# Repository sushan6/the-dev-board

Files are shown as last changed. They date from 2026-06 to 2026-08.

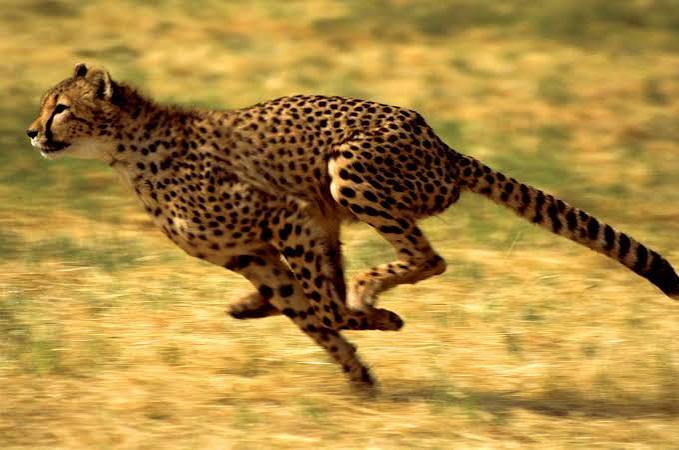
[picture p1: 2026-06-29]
assets/images (1).png

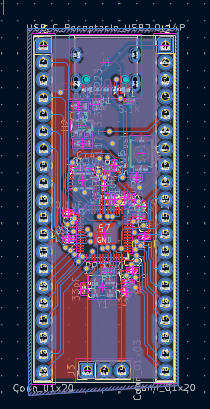
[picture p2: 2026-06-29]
assets/pcb image.PNG

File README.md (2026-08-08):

# Sushan's dev board 

This development board is designed to be a compact, reliable prototyping platform using the RP2040 microcontroller. It handles power management, high-speed external memory routing, and precise clocking, making it ready for custom embedded software applications.

## Key Features

* Microcontroller: Based on the RP2040 chip, bringing twin-core processing capabilities to a custom hardware layout.
* Power Management: Driven by a modern USB-C receptacle for both power delivery and data interfacing, regulated down to a clean three-point-three volts using an onboard linear regulator.
* External Storage: Incorporates external flash memory connected over a quad serial peripheral interface, giving ample room for large programs and data storage.
* Clock Source: Utilises a twelve megahertz crystal oscillator circuit to ensure stable and highly accurate clock timing for the microcontroller.
* Input and Output Breakouts: Exposes general-purpose input/output pins to dual-row pin headers, providing quick access for connecting sensors, displays, and external components.
* There are 40 pins externally for data
* SD card reader 
## Hardware Design and Previews

### Schematic Layout
The schematic is divided into clean functional blocks including power management, flash memory wiring, crystal clock generation, and pin mappings. 

schematics1

---

### PCB Layout and 3D Visualisations
The physical layout focuses on tight trace routing, proper decoupling capacitor placement for power stability, and optimised signal paths. 

pcb image1

#### Board Front View

front-3d-pcb1

#### Board Back View

back-3d-pcb1

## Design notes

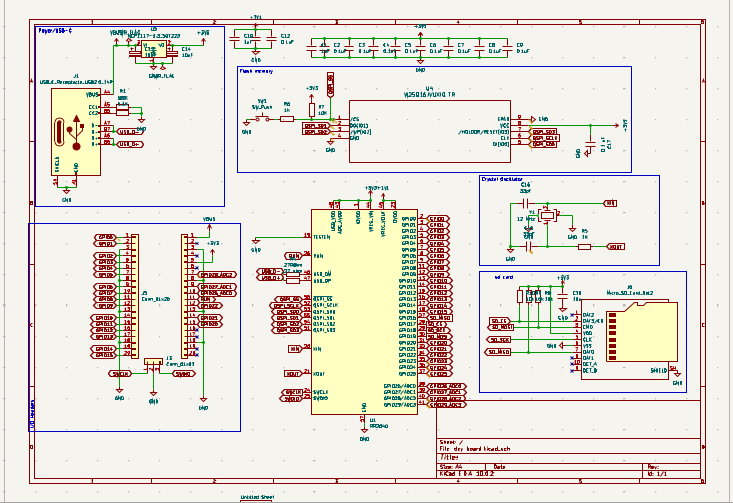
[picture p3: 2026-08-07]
assets/schematics.PNG

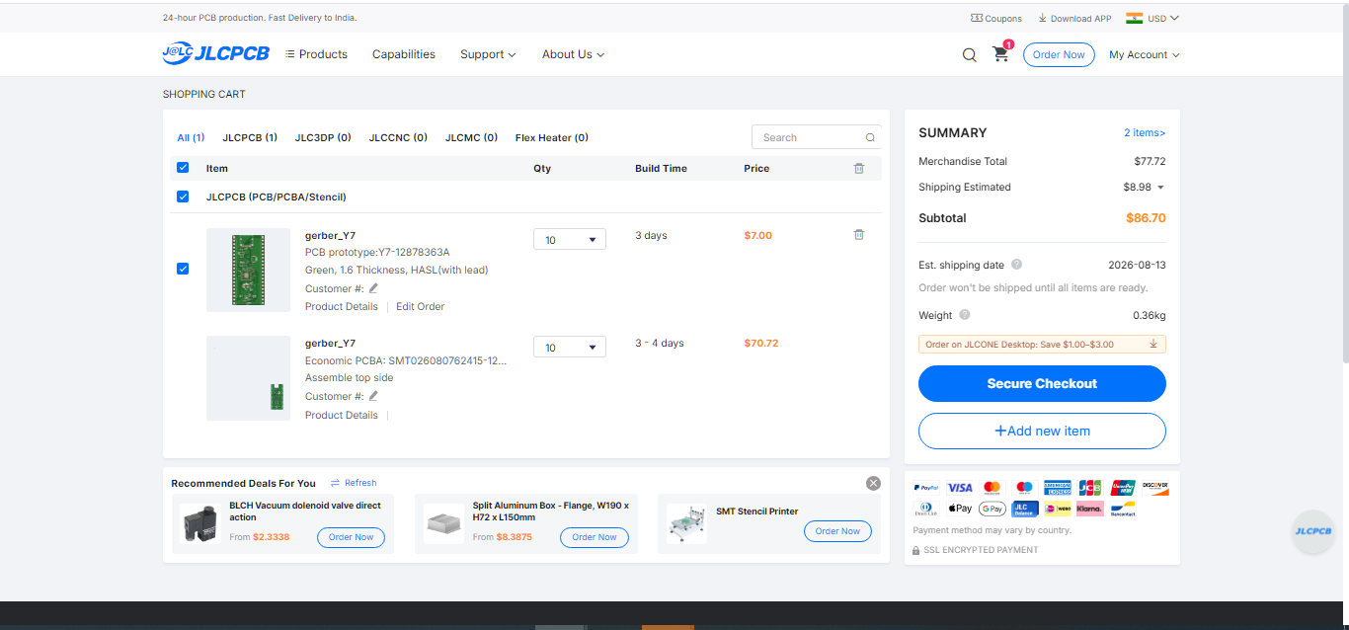
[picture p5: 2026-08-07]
assets/cart-jlcpcb.PNG

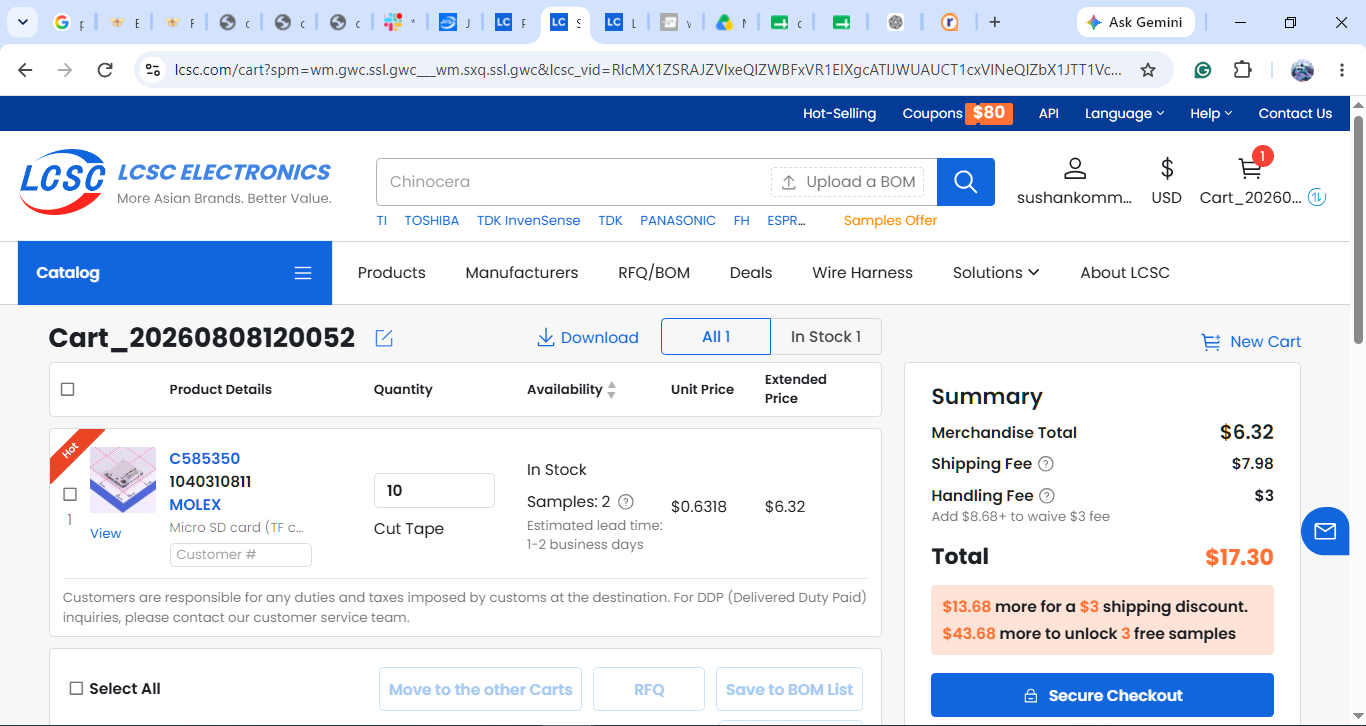
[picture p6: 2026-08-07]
assets/cart-lcsc.PNG

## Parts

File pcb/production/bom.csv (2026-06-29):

Designator | Footprint | Quantity | Value | LCSC Part #
C1, C10 | 0402 | 2 | 1uF
C11, C12, C2, C3, C4, C5, C6, C7, C8, C9 | 0402 | 10 | 0.1uF
C13, C14 | 0603 | 2 | 10uF
C15, C16 | 0402 | 2 | 33pF
C17 | 0402 | 1 | 0.1 uF
J1 | USB_C_Receptacle_HRO_TYPE-C-31-M-12 | 1 | USB_C_Receptacle_USB2.0_14P
J2, J5 | PinHeader_1x20_P2.54mm_Vertical | 2 | Conn_01x20
J3 | PinHeader_1x03_P2.54mm_Vertical | 1 | Conn_01x03
R1, R2 | 0402 | 2 | 5.1K
R3, R4 | 0402 | 2 | 27 ohm
R5, R6 | 0402 | 2 | 1K
R7 | 0402 | 1 | 10K
SW1 | SW_Push_SPST_NO_Alps_SKRK | 1 | SW_Push
U1 | QFN-56-1EP_7x7mm_P0.4mm_EP3.2x3.2mm | 1 | RP2040
U2 | SOT-23 | 1 | NCP1117-3.3_SOT223
U4 | Winbond_USON-8-1EP_3x2mm_P0.5mm_EP0.2x1.6mm | 1 | W25Q16JVUXIQ TR
Y1 | Crystal_SMD_3225-4Pin_3.2x2.5mm | 1 | 12 MHz

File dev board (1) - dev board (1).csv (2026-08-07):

Id | Designator | Footprint | Quantity | Comment | Supplier and ref
1 | C1, C10 | C_0402_1005Metric | 2 | 1uF
2 | C2, C3, C4, C5, C6, C7, C8, C9, C11, C12 | C_0402_1005Metric | 10 | 0.1uF
3 | C13, C14 | C_0603_1608Metric | 2 | 10uF
4 | C15, C16 | C_0402_1005Metric | 2 | 33pF
5 | C17 | C_0402_1005Metric | 1 | 0.1 uF
6 | C18 | C_0603_1608Metric | 1 | 10u
7 | C19 | C_0402_1005Metric | 1 | 0.1uf
8 | J1 | USB_C_Receptacle_HRO_TYPE-C-31-M-12 | 1 | USB_C_Receptacle_USB2.0_14P
9 | J2, J5 | PinHeader_1x20_P2.54mm_Vertical | 2 | Conn_01x20
10 | J3 | PinHeader_1x03_P1.27mm_Vertical_SMD_Pin1Left | 1 | Conn_01x03
11 | J4 | microSD_HC_Molex_104031-0811 | 1 | 104031-0811
12 | R1, R2 | R_0402_1005Metric | 2 | 5.1K
13 | R3, R4 | R_0402_1005Metric | 2 | 27 ohm
14 | R5 | R_0402_1005Metric | 1 | 1K
15 | R6 | R_0402_1005Metric | 1 | 1k
16 | R7 | R_0402_1005Metric | 1 | 10K
17 | R8, R9, R10 | R_0402_1005Metric | 3 | 10k
18 | SW1 | SW_Push_SPST_NO_Alps_SKRK | 1 | SW_Push
19 | U1 | QFN-56-1EP_7x7mm_P0.4mm_EP3.2x3.2mm | 1 | RP2040
20 | U2 | SOT-23 | 1 | NCP1117-3.3_SOT223
21 | U4 | Winbond_USON-8-1EP_3x2mm_P0.5mm_EP0.2x1.6mm | 1 | W25Q16JVUXIQ TR
22 | Y1 | Crystal_SMD_3225-4Pin_3.2x2.5mm | 1 | 12 MHz

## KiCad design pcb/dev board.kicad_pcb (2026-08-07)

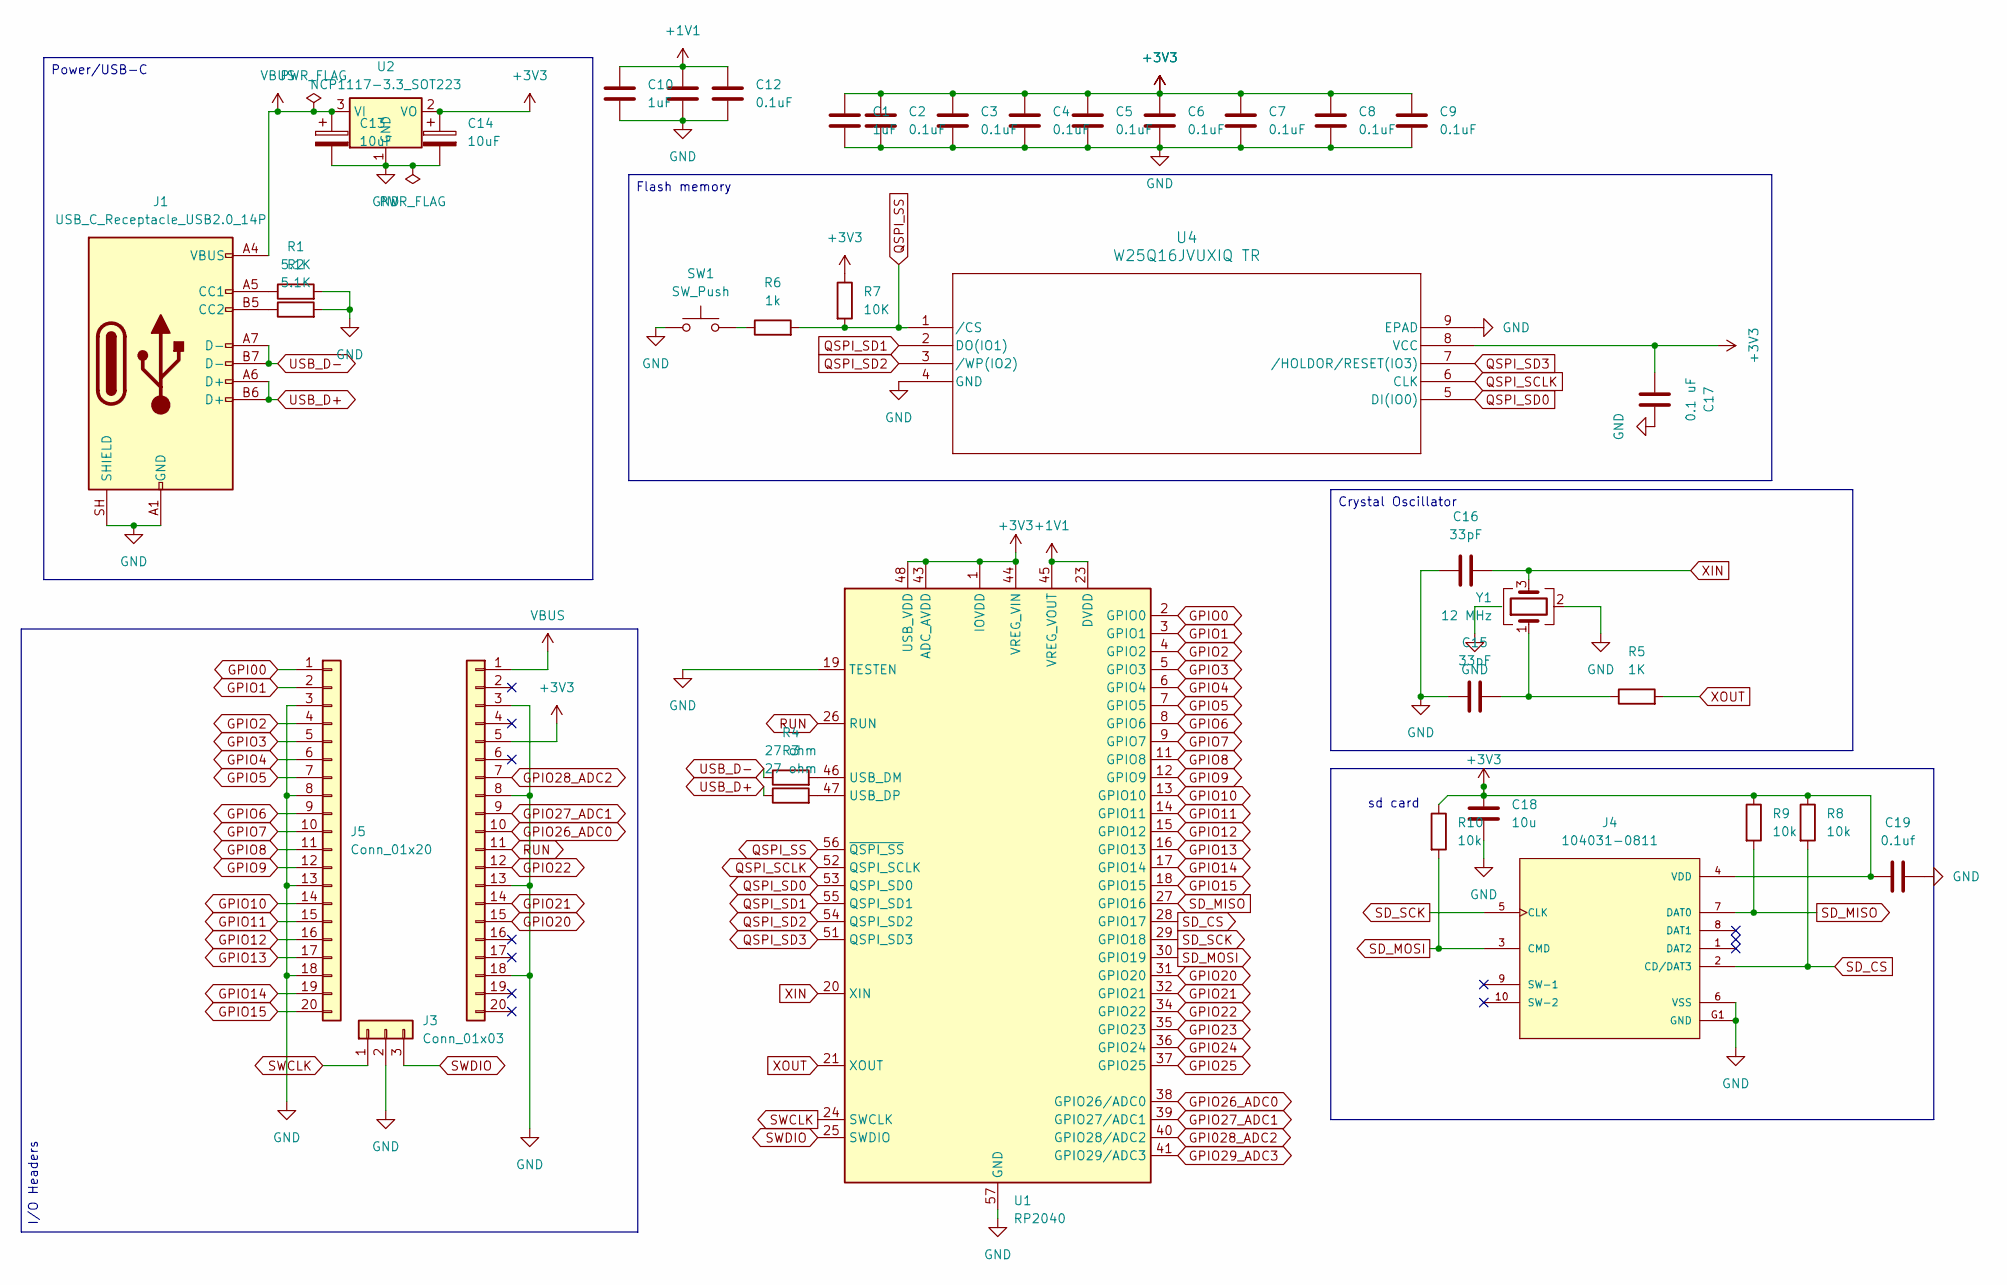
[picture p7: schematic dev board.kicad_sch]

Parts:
C1, C10: 1uF; C_0402_1005Metric
C2, C3, C4, C5, C6, C7, C8, C9, C11, C12: 0.1uF; C_0402_1005Metric
C13, C14: 10uF; C_0603_1608Metric
C15, C16: 33pF; C_0402_1005Metric
C17: 0.1 uF; C_0402_1005Metric
C18: 10u; C_0603_1608Metric
C19: 0.1uf; C_0402_1005Metric
J1: USB_C_Receptacle_USB2.0_14P; USB_C_Receptacle_HRO_TYPE-C-31-M-12
J2, J5: Conn_01x20; PinHeader_1x20_P2.54mm_Vertical
J3: Conn_01x03; PinHeader_1x03_P1.27mm_Vertical_SMD_Pin1Left
J4: 104031-0811; microSD_HC_Molex_104031-0811; PARTREV B2
R1, R2: 5.1K; R_0402_1005Metric
R3, R4: 27 ohm; R_0402_1005Metric
R5: 1K; R_0402_1005Metric
R6: 1k; R_0402_1005Metric
R7: 10K; R_0402_1005Metric
R8, R9, R10: 10k; R_0402_1005Metric
SW1: SW_Push; SW_Push_SPST_NO_Alps_SKRK
U1: RP2040; QFN-56-1EP_7x7mm_P0.4mm_EP3.2x3.2mm
U2: NCP1117-3.3_SOT223; SOT-23
U4: W25Q16JVUXIQ TR; Winbond_USON-8-1EP_3x2mm_P0.5mm_EP0.2x1.6mm
Y1: 12 MHz; Crystal_SMD_3225-4Pin_3.2x2.5mm

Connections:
+1V1: C10.1, C11.1, C12.1, U1.23 (DVDD), U1.45 (VREG_VOUT), U1.50 (DVDD)
+3V3: C1.1, C2.1, C3.1, C4.1, C5.1, C6.1, C7.1, C8.1, C9.1, C14.1, C17.1, C18.1, C19.2, J2.5, J4.4 (VDD), R7.1, R8.1, R9.1, R10.1, U1.1 (IOVDD), U1.10 (IOVDD), U1.22 (IOVDD), U1.33 (IOVDD), U1.42 (IOVDD), U1.43 (ADC_AVDD), U1.44 (VREG_VIN), U1.48 (USB_VDD), U1.49 (IOVDD), U2.2 (VO), U4.8 (VCC)
GND: C1.2, C2.2, C3.2, C4.2, C5.2, C6.2, C7.2, C8.2, C9.2, C10.2, C11.2, C12.2, C13.2, C14.2, C15.1, C16.1, C17.2, C18.2, C19.1, J1.A1 (GND), J1.A12 (GND), J1.B1 (GND), J1.B12 (GND), J1.SH (SHIELD), J2.3, J2.8, J2.13, J2.18, J3.2, J4.6 (VSS), J4.G1 (GND), J4.G2 (GND), J4.G3 (GND), J4.G4 (GND), J5.3, J5.8, J5.13, J5.18, R1.2, R2.2, SW1.1, U1.19 (TESTEN), U1.57 (GND), U2.1 (GND), U4.4 (GND), U4.9 (EPAD), Y1.2 (G), Y1.4 (G)
GPI00: J5.1
GPI028_ADC2: U1.40 (GPIO28/ADC2)
GPIO0: U1.2 (GPIO0)
GPIO1: J5.2, U1.3 (GPIO1)
GPIO2: J5.4, U1.4 (GPIO2)
GPIO3: J5.5, U1.5 (GPIO3)
GPIO4: J5.6, U1.6 (GPIO4)
GPIO5: J5.7, U1.7 (GPIO5)
GPIO6: J5.9, U1.8 (GPIO6)
GPIO7: J5.10, U1.9 (GPIO7)
GPIO8: J5.11, U1.11 (GPIO8)
GPIO9: J5.12, U1.12 (GPIO9)
GPIO10: J5.14, U1.13 (GPIO10)
GPIO11: J5.15, U1.14 (GPIO11)
GPIO12: J5.16, U1.15 (GPIO12)
GPIO13: J5.17, U1.16 (GPIO13)
GPIO14: J5.19, U1.17 (GPIO14)
GPIO15: J5.20, U1.18 (GPIO15)
GPIO20: J2.15, U1.31 (GPIO20)
GPIO21: J2.14, U1.32 (GPIO21)
GPIO22: J2.12, U1.34 (GPIO22)
GPIO23: U1.35 (GPIO23)
GPIO24: U1.36 (GPIO24)
GPIO25: U1.37 (GPIO25)
GPIO26_ADC0: J2.10, U1.38 (GPIO26/ADC0)
GPIO27_ADC1: J2.9, U1.39 (GPIO27/ADC1)
GPIO28_ADC2: J2.7
GPIO29_ADC3: U1.41 (GPIO29/ADC3)
unnamed: C15.2, R5.1, Y1.1
unnamed: J1.A5 (CC1), R1.1
unnamed: J1.B5 (CC2), R2.1
unnamed: R6.1, SW1.2
unnamed: R4.2, U1.46 (USB_DM)
unnamed: R3.2, U1.47 (USB_DP)
QSPI_SCLK: U1.52 (QSPI_SCLK), U4.6 (CLK)
QSPI_SD0: U1.53 (QSPI_SD0), U4.5 (DI(IO0))
QSPI_SD1: U1.55 (QSPI_SD1), U4.2 (DO(IO1))
QSPI_SD2: U1.54 (QSPI_SD2), U4.3 (/WP(IO2))
QSPI_SD3: U1.51 (QSPI_SD3), U4.7 (/HOLDOR/RESET(IO3))
QSPI_SS: R6.2, R7.2, U1.56 (~QSPI_SS), U4.1 (/CS)
RUN: J2.11, U1.26 (RUN)
SD_CS: J4.2 (CD/DAT3), R8.2, U1.28 (GPIO17)
SD_MISO: J4.7 (DAT0), R9.2, U1.27 (GPIO16)
SD_MOSI: J4.3 (CMD), R10.2, U1.30 (GPIO19)
SD_SCK: J4.5 (CLK), U1.29 (GPIO18)
SWCLK: J3.1, U1.24 (SWCLK)
SWDIO: J3.3, U1.25 (SWDIO)
USB_D+: J1.A6 (D+), J1.B6 (D+), R3.1
USB_D-: J1.A7 (D-), J1.B7 (D-), R4.1
VBUS: C13.1, J1.A4 (VBUS), J1.A9 (VBUS), J1.B4 (VBUS), J1.B9 (VBUS), J2.1, U2.3 (VI)
XIN: C16.2, U1.20 (XIN), Y1.3
XOUT: R5.2, U1.21 (XOUT)

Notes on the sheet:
sd card
Power/USB-C
I/O Headers
Flash memory
Crystal Oscillator

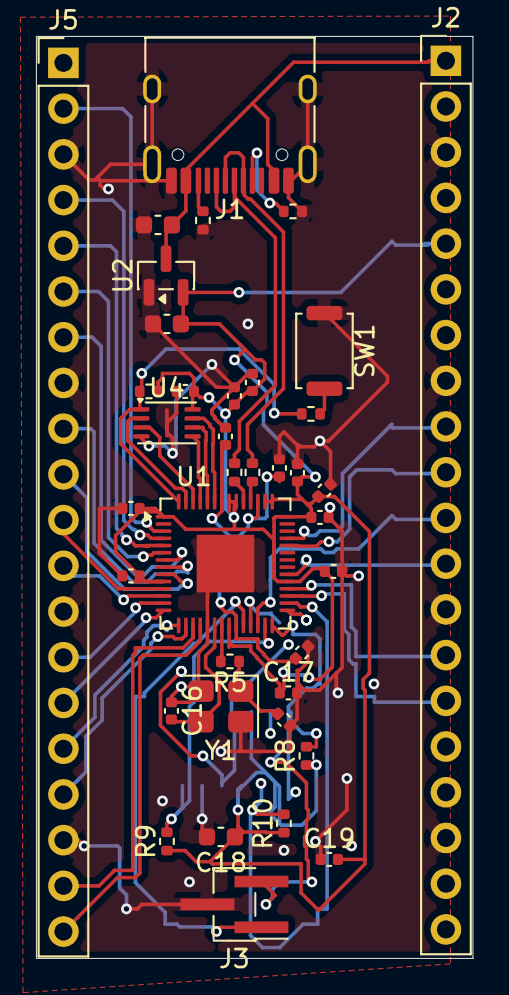
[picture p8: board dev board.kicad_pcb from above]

Board: 4 copper layers, 24.2 x 51.2 mm, 39 parts (1 on the bottom side), 47 nets.

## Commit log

2026-06-29 Update fmt.Println message from 'Hello' to 'Goodbye'
    [dev board.kicad_sch]
2026-06-29 Remove empty schematic file
2026-06-29 Your custom commit message here
    [bom.csv, dev board - dev board.csv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]
2026-06-29 Revise README for project overview and features
    Updated the README to provide a detailed project overview, key features, and hardware design information for the custom RP2040 development board.
2026-08-07 Update PCB files
    [dev board (1) - dev board (1).csv, dev board - dev board.csv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]
2026-08-07 Add SD card reader info and update PCB images
    Added information about the SD card reader and updated images for the PCB layout.
2026-11-10 Add Bill of Materials section to README
    Added a Bill of Materials (BOM) section with item details and cost summary.
2026-11-10 Revise component list in dev board CSV
    Updated component details including designators, quantities, and supplier links.
2026-11-10 Update dev board (1) - dev board (1).csv
